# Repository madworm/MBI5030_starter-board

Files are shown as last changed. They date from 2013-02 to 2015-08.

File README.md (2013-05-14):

MBI5030_starter-board
=====================

LAYOUT FILES: Simple breadboard starter board for the MBI5030. Includes 16 SMD LEDs for instant light. 

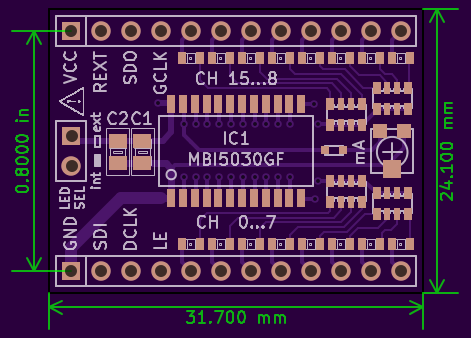
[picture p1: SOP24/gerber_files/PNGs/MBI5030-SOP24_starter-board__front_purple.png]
MBI5030-SOP24 starter board


You will find code for this project in [this](https://github.com/madworm/MBI5030_demo) repository.

---

Before having PC-boards made, please make sure you know about your manufacturer's peculiarities!
Especially drill-sizes and their tolerances may vary too much and give you trouble.

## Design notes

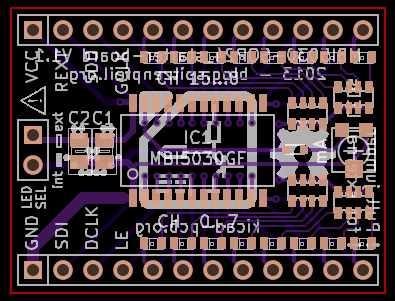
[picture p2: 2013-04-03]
SOP24/gerber_files/PNGs/MBI5030-SOP24_starter-board.png

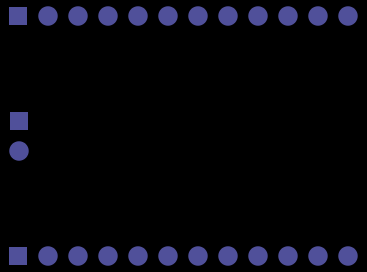
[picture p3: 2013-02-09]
SOP24/gerber_files/PNGs/MBI5030-SOP24_starter-board-B_Mask.gbs.png

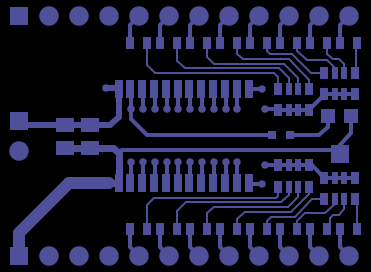
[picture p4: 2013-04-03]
SOP24/gerber_files/PNGs/MBI5030-SOP24_starter-board-F_Cu.gtl.png

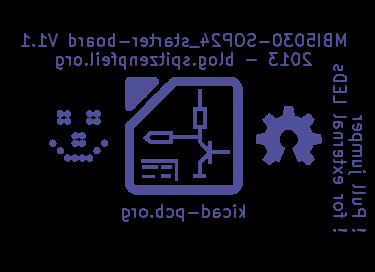
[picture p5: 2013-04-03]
SOP24/gerber_files/PNGs/MBI5030-SOP24_starter-board-B_SilkS.gbo.png

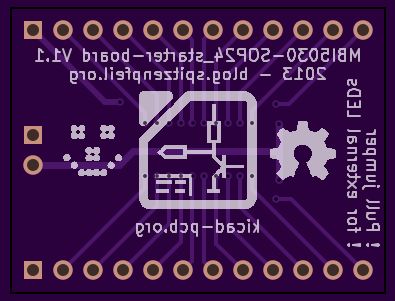
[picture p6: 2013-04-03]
SOP24/gerber_files/PNGs/MBI5030-SOP24_starter-board__back_purple.png

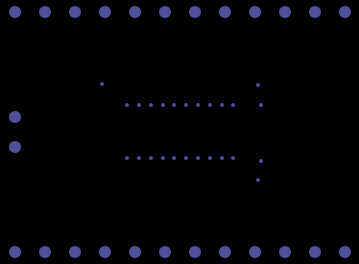
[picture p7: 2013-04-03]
SOP24/gerber_files/PNGs/MBI5030-SOP24_starter-board.drl.png

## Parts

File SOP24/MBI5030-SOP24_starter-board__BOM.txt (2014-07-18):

Bill of materials: "MBI5030-SOP24-starter-board"
------------------

C1	100nF 0805
C2	4.7µF 0805
D1-16	LED 0603
IC1	MBI5030 SOP24-300-1.00
JP1	0.1in header, male, 2-pin, jumper
P3	0.1in header, male, 12-pin
P4	0.1in header, male, 12-pin
R17	300R 0603
RP1-4	"1206*4" resistor array, 1k
RV1	potentiometer, 2k, TC33X-202

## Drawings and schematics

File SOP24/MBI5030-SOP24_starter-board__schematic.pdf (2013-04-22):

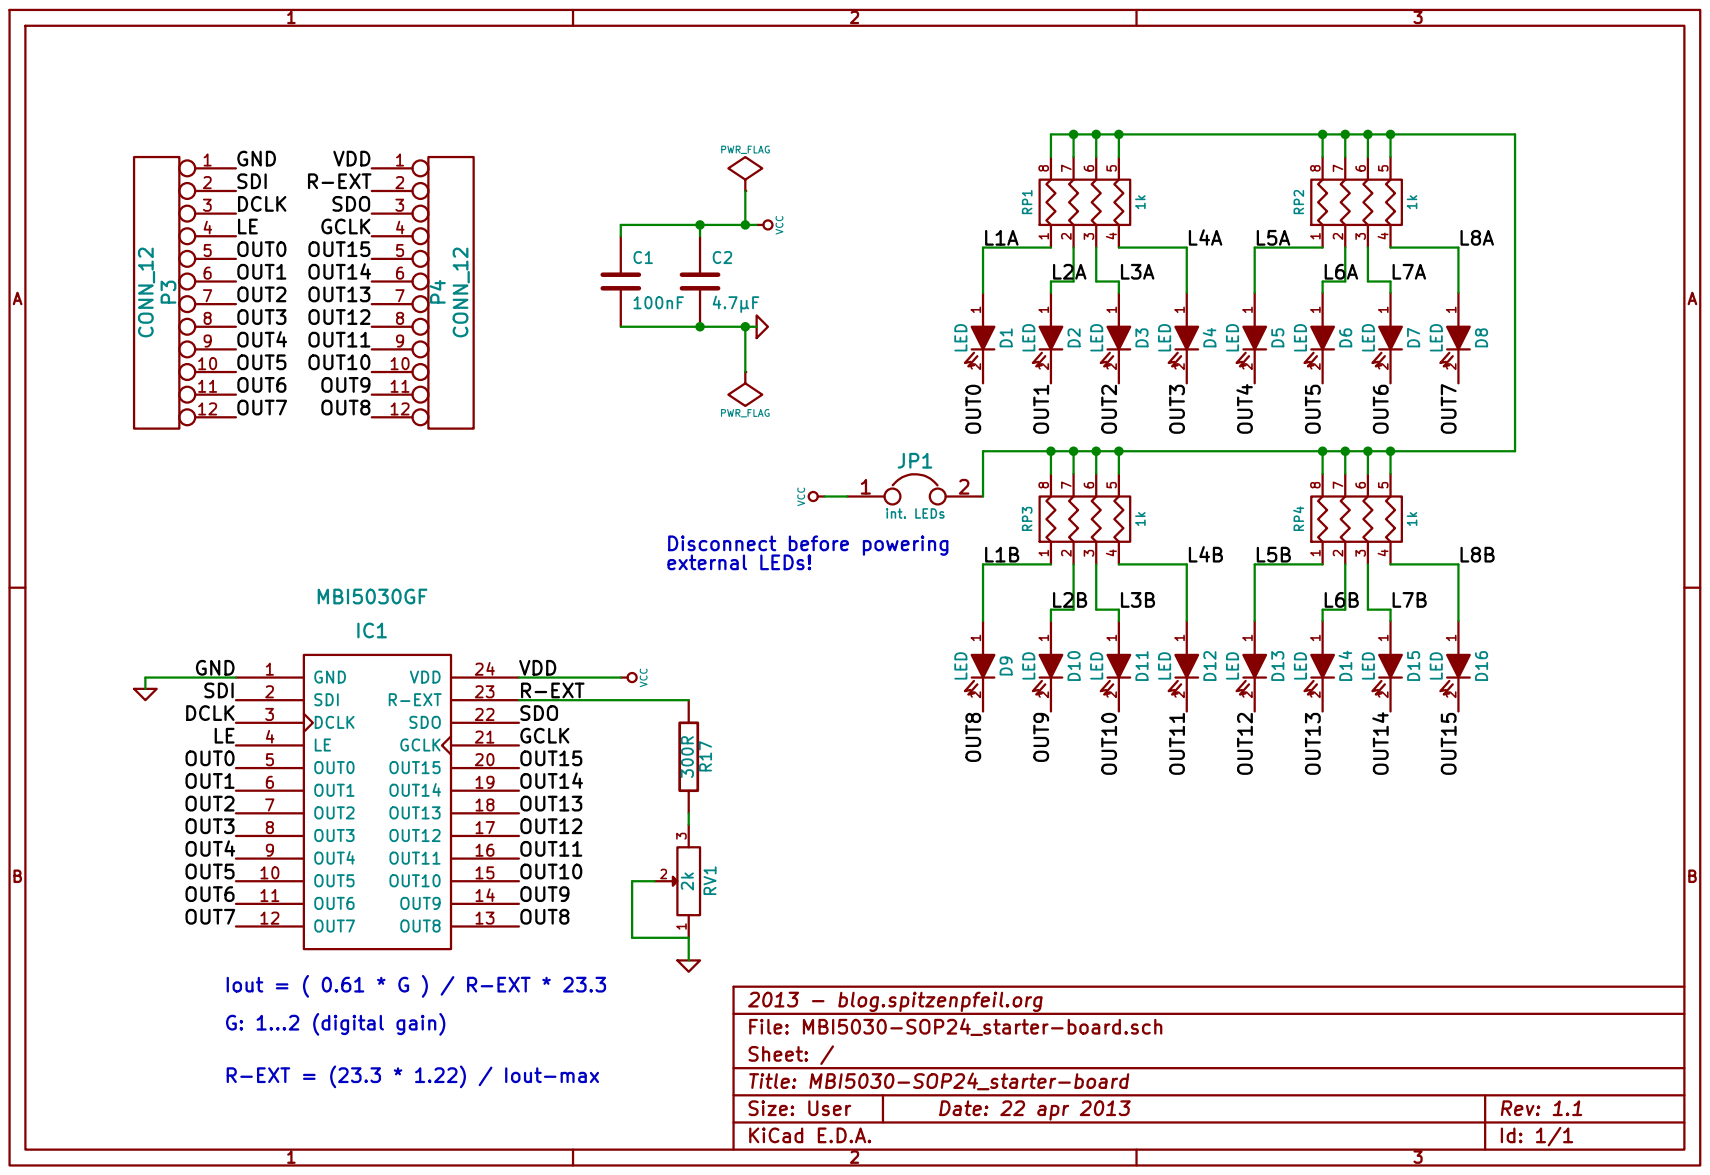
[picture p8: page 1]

int. LEDs Disconnect before powering

Size: User | | Rev: 1.1
KiCad E.D.A. | | Id: 1/1

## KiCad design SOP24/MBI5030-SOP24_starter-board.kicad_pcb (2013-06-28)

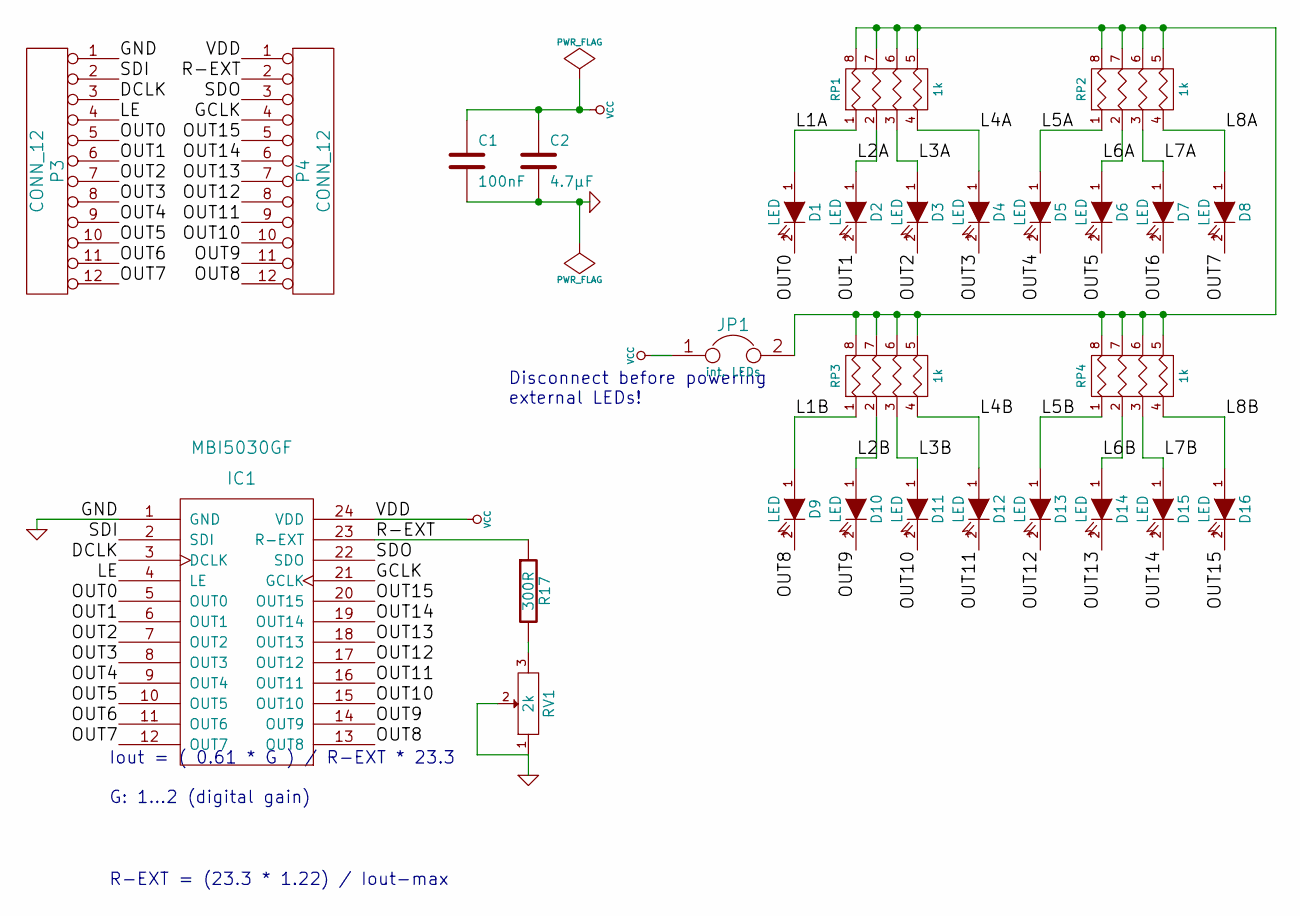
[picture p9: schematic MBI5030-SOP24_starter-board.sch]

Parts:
C1: 100nF
C2: 4.7µF
D1, D2, D3, D4, D5, D6, D7, D8, D9, D10, D11, D12, D13, D14, D15, D16: LED
IC1: MBI5030GF
JP1: int. LEDs
P3, P4: CONN_12
R17: 300R
RP1, RP2, RP3, RP4: 1k
RV1: 2k

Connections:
/DCLK: IC1.3 (DCLK), P3.3
/GCLK: IC1.21 (GCLK), P4.4
/L1A: D1.1 (A), RP1.1
/L1B: D9.1 (A), RP3.1
/L2A: D2.1 (A), RP1.2
/L2B: D10.1 (A), RP3.2
/L3A: D3.1 (A), RP1.3
/L3B: D11.1 (A), RP3.3
/L4A: D4.1 (A), RP1.4
/L4B: D12.1 (A), RP3.4
/L5A: D5.1 (A), RP2.1
/L5B: D13.1 (A), RP4.1
/L6A: D6.1 (A), RP2.2
/L6B: D14.1 (A), RP4.2
/L7A: D7.1 (A), RP2.3
/L7B: D15.1 (A), RP4.3
/L8A: D8.1 (A), RP2.4
/L8B: D16.1 (A), RP4.4
/LE: IC1.4 (LE), P3.4
/OUT0: D1.2 (K), IC1.5 (OUT0), P3.5
/OUT1: D2.2 (K), IC1.6 (OUT1), P3.6
/OUT2: D3.2 (K), IC1.7 (OUT2), P3.7
/OUT3: D4.2 (K), IC1.8 (OUT3), P3.8
/OUT4: D5.2 (K), IC1.9 (OUT4), P3.9
/OUT5: D6.2 (K), IC1.10 (OUT5), P3.10
/OUT6: D7.2 (K), IC1.11 (OUT6), P3.11
/OUT7: D8.2 (K), IC1.12 (OUT7), P3.12
/OUT8: D9.2 (K), IC1.13 (OUT8), P4.12
/OUT9: D10.2 (K), IC1.14 (OUT9), P4.11
/OUT10: D11.2 (K), IC1.15 (OUT10), P4.10
/OUT11: D12.2 (K), IC1.16 (OUT11), P4.9
/OUT12: D13.2 (K), IC1.17 (OUT12), P4.8
/OUT13: D14.2 (K), IC1.18 (OUT13), P4.7
/OUT14: D15.2 (K), IC1.19 (OUT14), P4.6
/OUT15: D16.2 (K), IC1.20 (OUT15), P4.5
/R-EXT: IC1.23 (R-EXT), P4.2, R17.1
/SDI: IC1.2 (SDI), P3.2
/SDO: IC1.22 (SDO), P4.3
GND: C1.2, C2.2, IC1.1 (GND), P3.1, RV1.1, RV1.2
unnamed: R17.2, RV1.3
unnamed: JP1.2, RP1.5 (R4), RP1.6 (R3), RP1.7 (R2), RP1.8 (R1), RP2.5 (R4), RP2.6 (R3), RP2.7 (R2), RP2.8 (R1), RP3.5 (R4), RP3.6 (R3), RP3.7 (R2), RP3.8 (R1), RP4.5 (R4), RP4.6 (R3), RP4.7 (R2), RP4.8 (R1)
VCC: C1.1, C2.1, IC1.24 (VDD), JP1.1, P4.1

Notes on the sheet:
Iout = ( 0.61 * G ) / R-EXT * 23.3 G: 1...2 (digital gain)
Disconnect before powering external LEDs!
R-EXT = (23.3 * 1.22) / Iout-max

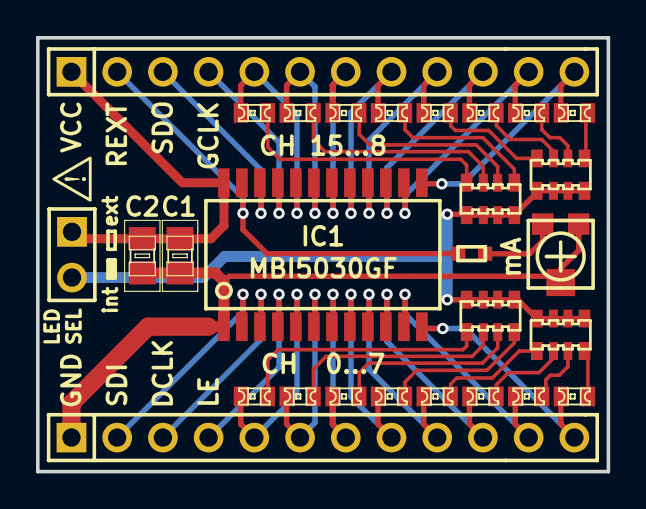
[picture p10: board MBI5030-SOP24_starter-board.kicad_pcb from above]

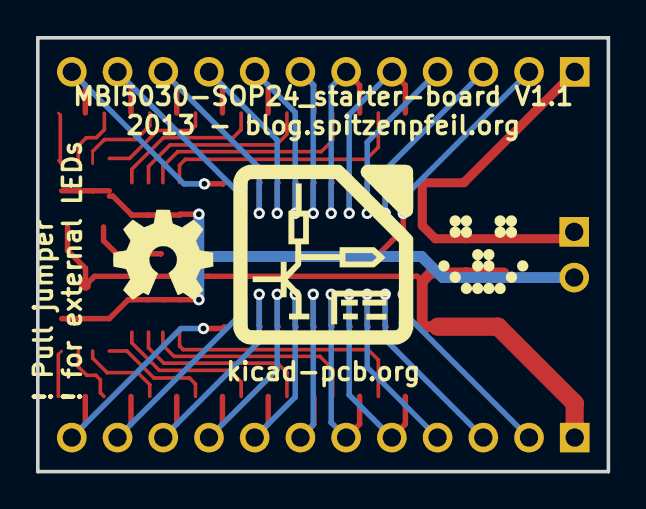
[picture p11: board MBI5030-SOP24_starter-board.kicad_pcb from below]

Board: 2 copper layers, 31.7 x 24.1 mm, 32 parts (3 on the bottom side), 42 nets.

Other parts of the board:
G1, G2, G3, G4: LOGO

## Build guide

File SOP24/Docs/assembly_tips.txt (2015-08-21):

* Flux, flux, flux...

* LED orientation:	The cathodes must point towards the header pins, which go into the chip (current sink).
			One way to achieve this is to have the cathodes point towards the jumper on the left.

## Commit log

2013-01-21 First doodles.
    [MBI5030-SOP24_starter-board.brd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]
2013-01-21 Shifted a silly trace to where it belongs.
    [MBI5030-SOP24_starter-board.brd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]
2013-01-21 Board shrink. 1 more free row of pins on the breadboard.
    [MBI5030-SOP24_starter-board.brd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]
2013-01-21 Added a board dimensions on a comment layer.
    [MBI5030-SOP24_starter-board.brd]
2013-01-21 Added a warning on B_SilkS to pull the jumper for external LEDs.
    This is especially important if their supply voltage is above VCC.
    [MBI5030-SOP24_starter-board-B_Mask.gbs, MBI5030-SOP24_starter-board-B_SilkS.gbo, MBI5030-SOP24_starter-board-Back.gbl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]
2013-01-21 Used smaller R0603 footprints and shifted them to better places.
    [MBI5030-SOP24_starter-board-B_Mask.gbs, MBI5030-SOP24_starter-board-B_SilkS.gbo, MBI5030-SOP24_starter-board-Back.gbl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]
2013-01-21 Silkscreen tweaks.
    [MBI5030-SOP24_starter-board-B_Mask.gbs, MBI5030-SOP24_starter-board-B_SilkS.gbo, MBI5030-SOP24_starter-board-Back.gbl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]
2013-01-22 Moved LED resistors. Tweezers are in fact not arbitrarily small.
    [MBI5030-SOP24_starter-board-B_Mask.gbs, MBI5030-SOP24_starter-board-B_SilkS.gbo, MBI5030-SOP24_starter-board-Back.gbl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]
2013-01-26 Much wider GND trace + minor tweaks to other traces.
    [MBI5030-SOP24_starter-board-B_Mask.gbs, MBI5030-SOP24_starter-board-B_SilkS.gbo, MBI5030-SOP24_starter-board-Back.gbl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]
2013-01-27 Behind the scenes stuff.
    [MBI5030-SOP24_starter-board.brd]
2013-01-29 Shifted LED-sel jumper + added a warning logo + info what to do.
    [MBI5030-SOP24_starter-board-B_Mask.gbs, MBI5030-SOP24_starter-board-B_SilkS.gbo, MBI5030-SOP24_starter-board-Back.gbl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]
2013-01-29 Added some text to F_SilkS.
    [MBI5030-SOP24_starter-board.brd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]
2013-02-04 Tweaks. Only affects silkscreen. Didn't recreate gerbers.
    [MBI5030-SOP24_starter-board.brd]
2013-02-09 Increased pad-size of headers (annular ring) + 0603 LED footprint (wider pads).
    [MBI5030-SOP24_starter-board-B_Mask.gbs, MBI5030-SOP24_starter-board-B_SilkS.gbo, MBI5030-SOP24_starter-board-Back.gbl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]
2013-04-01 Created a panel.
    [MBI5030-SOP24_starter-board__panel-B_Cu.gbl, MBI5030-SOP24_starter-board__panel-B_Mask.gbs, MBI5030-SOP24_starter-board__panel-B_SilkS.gbo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]
2013-04-03 Replaced 0603 resistors with 1206 4x resistor packs.
    [MBI5030-SOP24_starter-board-B_Cu.gbl, MBI5030-SOP24_starter-board-B_Mask.gbs, MBI5030-SOP24_starter-board-B_SilkS.gbo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]
2013-04-03 Upgraded the panel as well.
    [MBI5030-SOP24_starter-board__panel-B_Cu.gbl, MBI5030-SOP24_starter-board__panel-B_Mask.gbs, MBI5030-SOP24_starter-board__panel-B_SilkS.gbo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]
2013-04-05 Flipped one trace to F_Cu.
    [MBI5030-SOP24_starter-board-B_Cu.gbl, MBI5030-SOP24_starter-board-B_Mask.gbs, MBI5030-SOP24_starter-board-B_SilkS.gbo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]
2013-04-22 Added formula to calculate a SAFE R-EXT.
    [MBI5030-SOP24_starter-board.sch]
2013-06-28 Converted to new kicad board format.
    [MBI5030-SOP24_starter-board.brd, MBI5030-SOP24_starter-board.kicad_pcb]
2013-07-08 Added gerber file for: F_Paste.
    [MBI5030-SOP24_starter-board-F_Paste.gtp]
2014-07-18 Added simplified bill of materials file.
2014-07-18 Typo in BOM file.
2015-08-21 Added assembly tips.
